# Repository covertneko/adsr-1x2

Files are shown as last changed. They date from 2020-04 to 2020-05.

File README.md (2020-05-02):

# ADSR 1x2
This is a dual ADSR eurorack module using most of the available functions of the [Electric Druid ENVGEN8C](https://electricdruid.net/product/envgen8/).

The majority of the schematic is based on examples from the datasheet.

This module also includes an ATmega28P for the very critical purpose of animating the slider shaft leds in time with each envelope stage.

| Specs ||
|--- |---  |
| Size  | 12HP |
| Power | ?mA, +/-12V, 10 pin |
| Depth | 25mm |

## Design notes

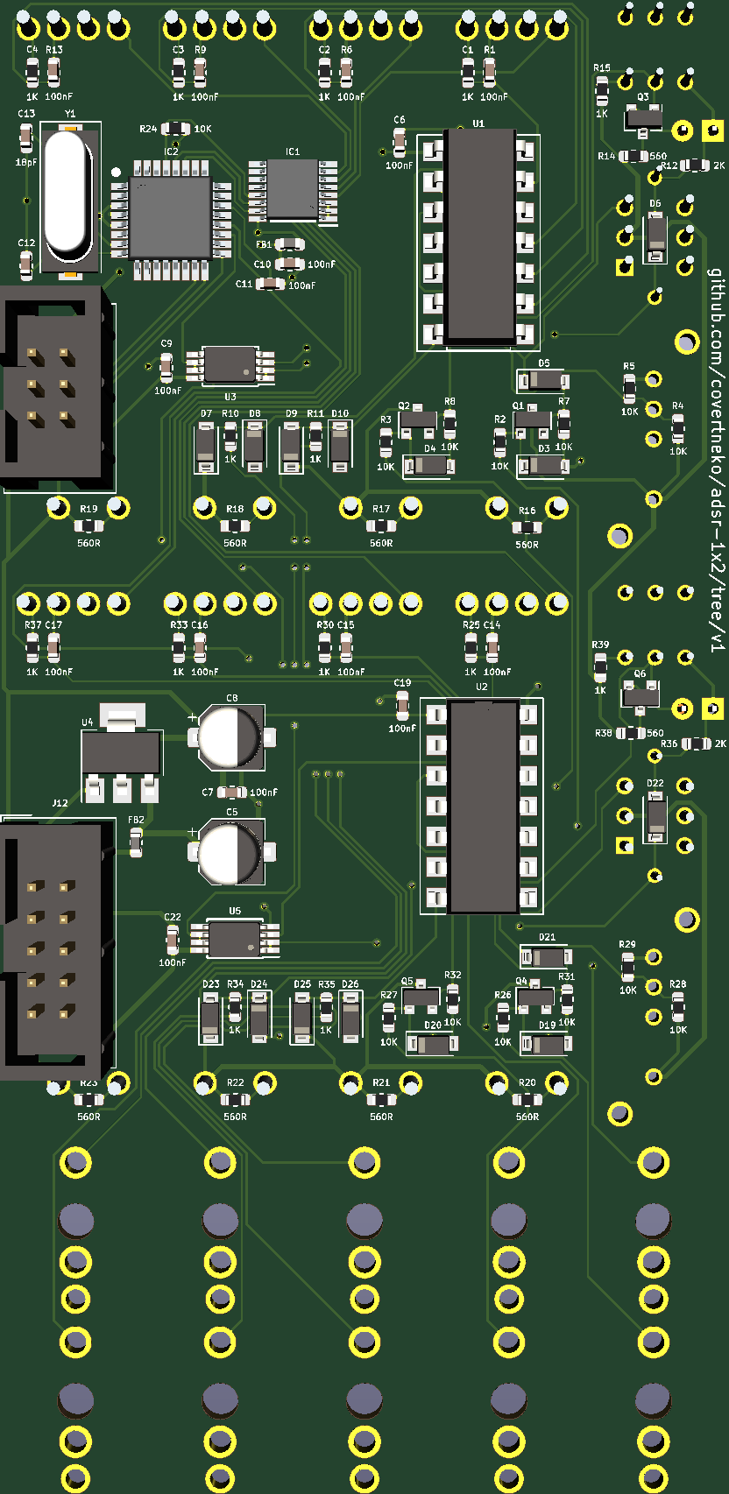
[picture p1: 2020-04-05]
board/adsr-1x2 back.png

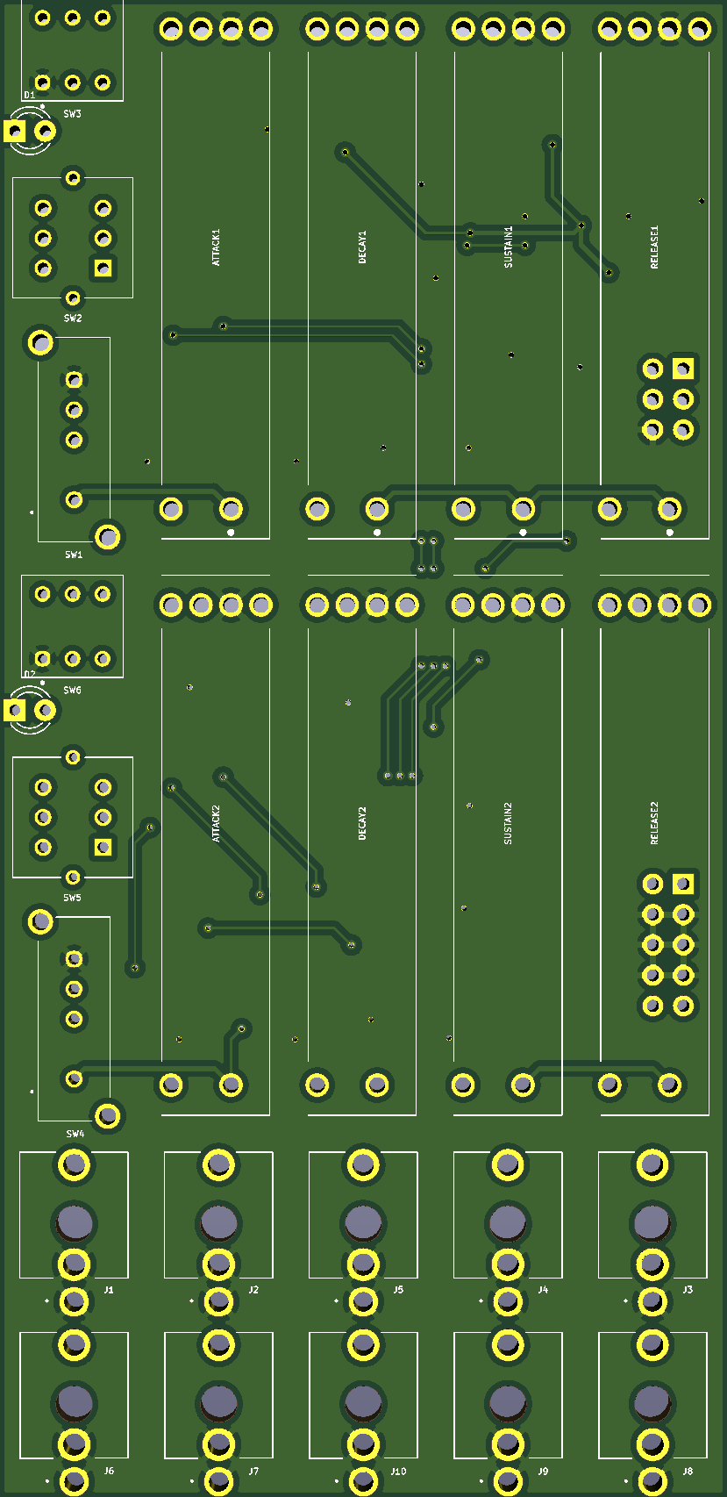
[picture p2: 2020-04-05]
board/adsr-1x2 front.png

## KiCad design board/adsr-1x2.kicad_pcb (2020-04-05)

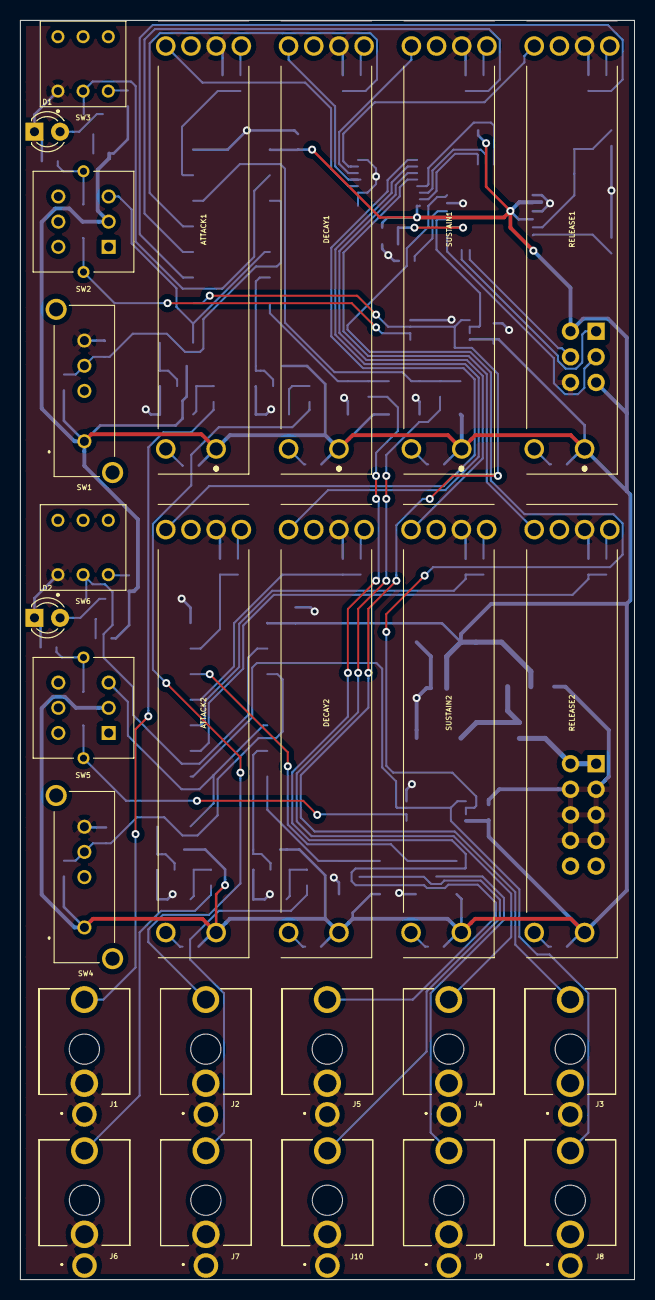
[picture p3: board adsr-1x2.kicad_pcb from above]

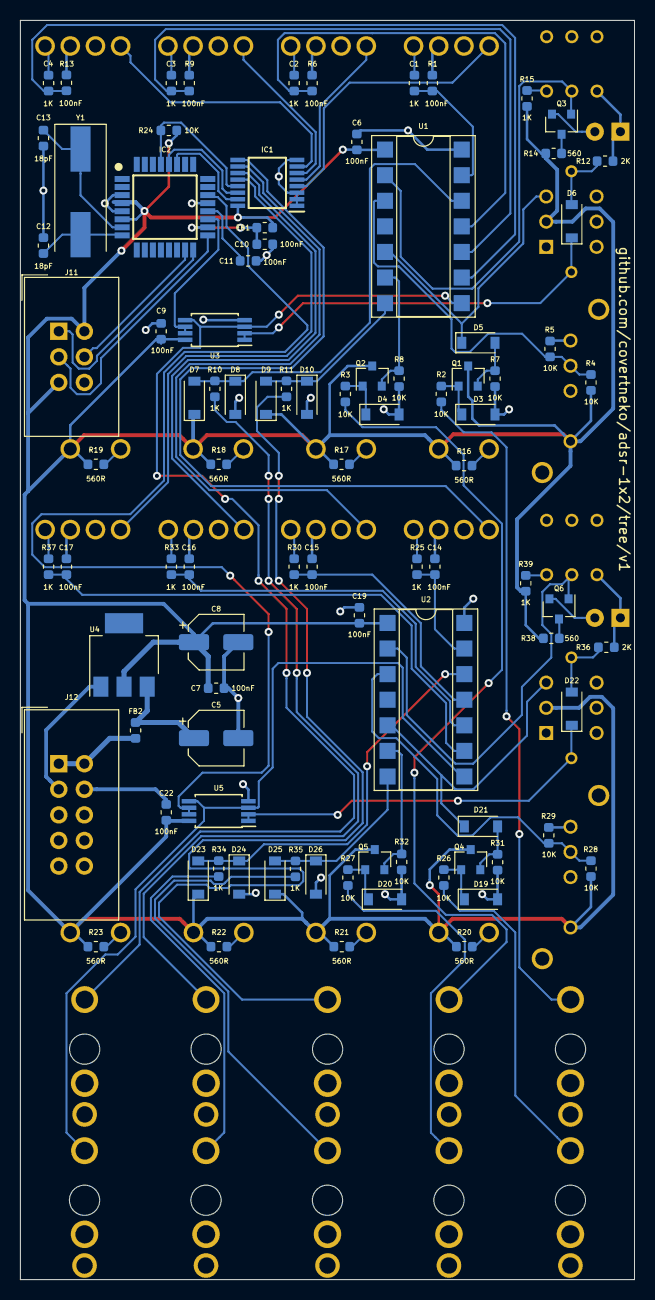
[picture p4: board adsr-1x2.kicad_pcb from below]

Board: 2 copper layers, 61.0 x 125.0 mm, 118 parts (92 on the bottom side), 86 nets.

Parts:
ATTACK1, ATTACK2: B10K; PTL3015A1102B1
C1, C2, C3, C4, C6, C7, C9, C10, C11, C14, C15, C16, C17, C19, C22: 100nF; C_0603_1608Metric
C5, C8: 22uF; CP_Elec_5x5.9
C12, C13: 18pF; C_0603_1608Metric
D1, D2: PUNCH; LED_D3.0mm
D3, D4, D5, D6, D19, D20, D21, D22: 1N4148W; D_SOD-123
D7, D8, D9, D10, D23, D24, D25, D26: 1N5819; D_SOD-123
DECAY1, DECAY2: B10K; PTL3015A1102B1
FB1, FB2: FERRITE; L_0603_1608Metric
IC1: TLC59208FIPWR; SOP65P640X120-16N
IC2: ATMEGA328P-AU; QFP80P900X900X120-32N
J1, J6: GATE; PJ301M
J2, J7: RETRIG; PJ301M
J3, J8: ENV; PJ301M
J4, J9: LEVEL; PJ301M
J5, J10: TIME; PJ301M
J11: AVR-ISP-6; IDC-Header_2x03_P2.54mm_Vertical
J12: POWER; IDC-Header_2x05_P2.54mm_Vertical
Q1, Q2, Q3, Q4, Q5, Q6: MMBT3904; SOT-23
R1, R6, R9, R10, R11, R13, R15, R25, R30, R33, R34, R35, R37, R39: 1K; R_0603_1608Metric
R2, R3, R4, R5, R7, R8, R24, R26, R27, R28, R29, R31, R32: 10K; R_0603_1608Metric
R12, R36: 2K; R_0603_1608Metric
R14, R38: 560; R_0603_1608Metric
R16, R17, R18, R19, R20, R21, R22, R23: 560R; R_0603_1608Metric
RELEASE1, RELEASE2: B10K; PTL3015A1102B1
SUSTAIN1, SUSTAIN2: B10K; PTL3015A1102B1
SW1, SW4: MODE; OS103012MU1QP1
SW2, SW5: TRIGGER; LP4EE1PBCTR
SW3, SW6: PUNCH; TL2201EEYA
U1, U2: ENVGEN8C; DIP-14_W7.62mm_SMDSocket_SmallPads
U3, U5: TL072; TSSOP-8_4.4x3mm_P0.65mm
U4: LM1117-5.0; SOT-223
Y1: 20MHz; Crystal_SMD_HC49-SD

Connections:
+5V: ATTACK1.3, ATTACK2.3, C6.1, C7.1, C8.1, C9.2, C19.1, C22.2, D7.1, D9.1, D23.1, D25.1, DECAY1.3, DECAY2.3, FB1.2, IC1.16, IC2.4, IC2.6, J11.2, J11.5, Q1.3, Q2.3, Q4.3, Q5.3, R4.1, R14.2, R15.1, R16.1, R17.1, R18.1, R19.1, R20.1, R21.1, R22.1, R23.1, R24.1, R28.1, R38.2, R39.1, RELEASE1.3, RELEASE2.3, SUSTAIN1.3, SUSTAIN2.3, SW1.1, SW2.2, SW4.1, SW5.2, U1.1, U2.1, U3.8, U4.2, U5.8
+12V: C5.1, FB2.2, U4.3
/ADSR1/ATTACK: C1.1, R1.2, U1.13
/ADSR1/DECAY: C2.1, R6.2, U1.11
/ADSR1/ENV: J3.3, U1.8, U3.3, U3.5
/ADSR1/GATE: D5.1, SW2.3, U1.5
/ADSR1/LEVEL: D7.2, D8.1, R10.1, U1.12
/ADSR1/MODE: R4.2, R5.1, SW1.3, U1.3
/ADSR1/PUNCH: Q3.1, SW3.2, U1.2
/ADSR1/RELEASE: C4.1, R13.2, U1.9
/ADSR1/RETRIG: Q2.2, R8.1, U1.6
/ADSR1/SUSTAIN: C3.1, R9.2, U1.10
/ADSR1/TIME: D9.2, D10.1, R11.1, U1.7
/ADSR2/ATTACK: C14.1, R25.2, U2.13
/ADSR2/DECAY: C15.1, R30.2, U2.11
/ADSR2/ENV: J8.3, U2.8, U5.3, U5.5
/ADSR2/GATE: D21.1, SW5.3, U2.5
/ADSR2/LEVEL: D23.2, D24.1, R34.1, U2.12
/ADSR2/MODE: R28.2, R29.1, SW4.3, U2.3
/ADSR2/PUNCH: Q6.1, SW6.2, U2.2
/ADSR2/RELEASE: C17.1, R37.2, U2.9
/ADSR2/RETRIG: Q5.2, R32.1, U2.6
/ADSR2/SUSTAIN: C16.1, R33.2, U2.10
/ADSR2/TIME: D25.2, D26.1, R35.1, U2.7
/LEDS/ENV1: IC2.19, U3.6, U3.7
/LEDS/ENV2: IC2.22, U5.6, U5.7
/LEDS/LED0: ATTACK1.E1, IC1.4
/LEDS/LED1: DECAY1.E1, IC1.5
/LEDS/LED2: IC1.6, SUSTAIN1.E1
/LEDS/LED3: IC1.7, RELEASE1.E1
/LEDS/LED4: ATTACK2.E1, IC1.9
/LEDS/LED5: DECAY2.E1, IC1.10
/LEDS/LED6: IC1.11, SUSTAIN2.E1
/LEDS/LED7: IC1.12, RELEASE2.E1
/LEDS/MISO: IC2.16, J11.1
/LEDS/MOSI: IC2.15, J11.4
/LEDS/SCK: IC2.17, J11.3
GND: ATTACK1.1, ATTACK2.1, C1.2, C2.2, C3.2, C4.2, C5.2, C6.2, C7.2, C8.2, C9.1, C10.1, C11.1, C12.1, C13.1, C14.2, C15.2, C16.2, C17.2, C19.2, C22.1, D1.1, D2.1, D3.2, D4.2, D8.2, D10.2, D19.2, D20.2, D24.2, D26.2, DECAY1.1, DECAY2.1, IC1.1, IC1.2, IC1.3, IC1.8, IC2.3, IC2.5, IC2.21, J1.1, J1.2, J2.1, J2.2, J3.1, J4.1, J4.2, J5.1, J5.2, J6.1, J6.2, J7.1, J7.2, J8.1, J9.1, J9.2, J10.1, J10.2, J11.6, J12.3, J12.4, J12.5, J12.6, J12.7, J12.8, R5.2, R7.2, R8.2, R12.1, R29.2, R31.2, R32.2, R36.1, RELEASE1.1, RELEASE2.1, SUSTAIN1.1, SUSTAIN2.1, SW1.4, SW3.1, SW4.4, SW6.1, U1.14, U2.14, U3.4, U4.1, U5.4
unnamed: ATTACK1.2, R1.1
unnamed: ATTACK1.B1, R16.2
unnamed: ATTACK2.2, R25.1
unnamed: ATTACK2.B1, R20.2
unnamed: C10.2, FB1.1, IC2.18
unnamed: C11.2, IC2.20
unnamed: C12.2, IC2.8, Y1.2
unnamed: C13.2, IC2.7, Y1.1
unnamed: D1.2, Q3.2
unnamed: D2.2, Q6.2
unnamed: D3.1, Q1.1, R2.2
unnamed: D4.1, Q2.1, R3.2
unnamed: D5.2, Q1.2, R7.1
unnamed: D6.1, SW2.L1, U3.1, U3.2
unnamed: D6.2, R12.2, SW2.L2
unnamed: D19.1, Q4.1, R26.2
unnamed: D20.1, Q5.1, R27.2
unnamed: D21.2, Q4.2, R31.1
unnamed: D22.1, SW5.L1, U5.1, U5.2
unnamed: D22.2, R36.2, SW5.L2
unnamed: DECAY1.2, R6.1
unnamed: DECAY1.B1, R17.2
unnamed: DECAY2.2, R30.1
unnamed: DECAY2.B1, R21.2
unnamed: FB2.1, J12.1, J12.2
unnamed: IC1.13, IC2.29, R24.2
unnamed: IC1.14, IC2.28
unnamed: IC1.15, IC2.27
unnamed: J1.3, R2.1
unnamed: J2.3, R3.1
unnamed: J4.3, R10.2
unnamed: J5.3, R11.2
unnamed: J6.3, R26.1
unnamed: J7.3, R27.1
unnamed: J9.3, R34.2
unnamed: J10.3, R35.2
unnamed: Q3.3, R14.1
unnamed: Q6.3, R38.1
unnamed: R9.1, SUSTAIN1.2
unnamed: R13.1, RELEASE1.2
unnamed: R15.2, SW3.3
unnamed: R18.2, SUSTAIN1.B1
unnamed: R19.2, RELEASE1.B1
unnamed: R22.2, SUSTAIN2.B1
unnamed: R23.2, RELEASE2.B1
unnamed: R33.1, SUSTAIN2.2
unnamed: R37.1, RELEASE2.2
unnamed: R39.2, SW6.3
